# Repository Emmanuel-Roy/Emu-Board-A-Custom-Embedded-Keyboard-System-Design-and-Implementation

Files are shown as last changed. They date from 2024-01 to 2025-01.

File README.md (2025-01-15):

# Emu-Board: A Custom Embedded Keyboard System Design and Implementation
A Custom Keyboard Designed *Almost Entirely From Scratch.

Images:





Things Designed From Scratch

  -PCB (Using KiCad and ScottoKeebs Footprint and Symbol Libraries)

  -Casing (Using Ruby to laser cut the acrylic)

  -Keyboard Matrix Firmware Code (Using KMK Firmware to do the majority of the processing.)

Components Bought:

  -77 Key Switches (Boba U4T)

  -77 1N4148 Diodes

  -Durock Plate Mounted Stabilizers

  -Raspberry Pi Pico

  -Keycaps

  -M.2 Screws and Standoffs

I used the following resources to help with this project.

  -https://matt3o.com/anatomy-of-a-keyboard/

  -http://www.keyboard-layout-editor.com/

  -http://builder.swillkb.com/

  -https://github.com/joe-scotto/scottokeebs/tree/main/Extras/ScottoKicad

  -https://www.youtube.com/watch?v=8WXpGTIbxlQ

  -https://www.youtube.com/watch?v=8WXpGTIbxlQ

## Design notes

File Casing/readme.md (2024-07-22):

Use trotec ruby to lazer cut.

The height of the raspberry pi is roughy 54 mm, I a rectangle to account for it in kiCAD.

I also made the space between the screw posts and outer layer of wood too small, I'd recommend more clearance because my standoff have mostly broken off.

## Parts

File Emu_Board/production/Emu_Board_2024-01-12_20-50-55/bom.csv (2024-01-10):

Designator | Footprint | Quantity | Value | LCSC Part #
D1, D10, D11, D12, D13, D14, D15, D16, D17, D18, D19, D2, D20, D21, D22, D23, D24, D25, D26, D27, D28, D29, D3, D30, D31, D32, D33, D34, D35, D36, D37, D38, D39, D4, D40, D41, D42, D43, D44, D45, D46, D47, D48, D49, D5, D50, D51, D52, D53, D54, D55, D56, D57, D58, D59, D6, D60, D61, D62, D63, D64, D65, D66, D67, D68, D69, D7, D70, D71, D72, D73, D74, D75, D76, D77, D8, D9 | Diode_DO-35 | 77 | Diode
S1, S10, S11, S12, S13, S14, S15, S16, S17, S18, S19, S2, S20, S21, S22, S23, S24, S25, S26, S29, S3, S30, S31, S32, S33, S34, S35, S36, S37, S38, S39, S4, S40, S43, S44, S45, S46, S47, S48, S49, S5, S50, S51, S52, S53, S56, S57, S58, S59, S6, S60, S61, S62, S63, S64, S65, S67, S7, S75, S76, S77, S8, S9 | MX_PCB_1.00u | 63 | Keyswitch
S27 | MX_PCB_2.00u | 1 | Keyswitch
S28, S41 | MX_PCB_1.50u | 2 | Keyswitch
S42 | MX_PCB_1.75u | 1 | Keyswitch
S54, S55 | MX_PCB_2.25u | 2 | Keyswitch
S66 | MX_PCB_2.75u | 1 | Keyswitch
S68, S69, S70, S72, S73, S74 | MX_PCB_1.25u | 6 | Keyswitch
S71 | MX_PCB_6.25u | 1 | Keyswitch
U2 | Raspberry_Pi_Pico | 1 | Raspberry_Pi_Pico

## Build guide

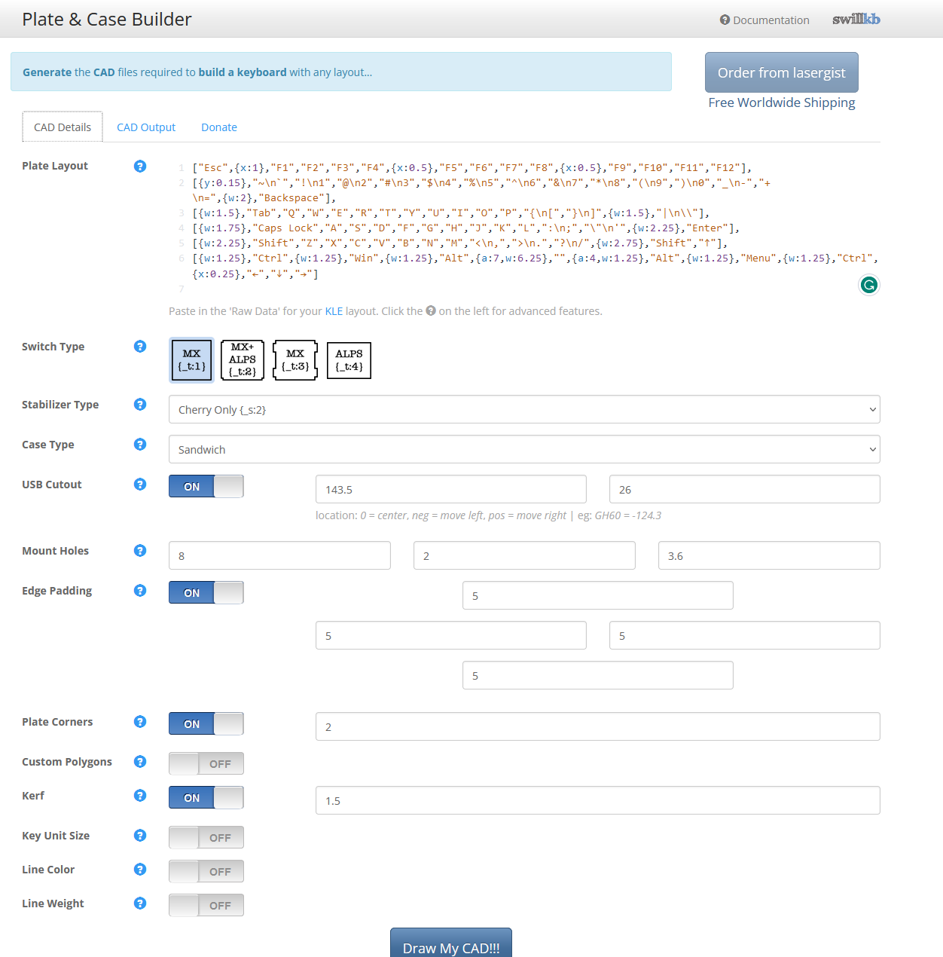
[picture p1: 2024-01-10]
CAD Requirementrs (Find the Kerf of the lazer printers).png

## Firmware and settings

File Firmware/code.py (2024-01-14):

import board    
from kmk.kmk_keyboard import KMKKeyboard
from kmk.keys import KC
from kmk.extensions.media_keys import MediaKeys


EMUBOARD = KMKKeyboard()

EMUBOARD.col_pins = (board.GP6,board.GP7,board.GP8,board.GP9,board.GP10,board.GP11,board.GP12,board.GP13,board.GP14,board.GP15,board.GP16,board.GP17,board.GP18,board.GP19)
EMUBOARD.row_pins = (board.GP0,board.GP1,board.GP2,board.GP3,board.GP4,board.GP5)
EMUBOARD.extensions.append(MediaKeys())


EMUBOARD.keymap = [
    [KC.ESCAPE, KC.F1, KC.F2, KC.F3, KC.F4, KC.F5, KC.F6, KC.F7, KC.F8, KC.F9, KC.F10, KC.F11, KC.F12, KC.NO,
     KC.GRAVE, KC.N1, KC.N2, KC.N3, KC.N4, KC.N5, KC.N6, KC.N7, KC.N8, KC.N9, KC.N0, KC.MINUS, KC.EQUAL, KC.BSPACE,
     KC.TAB, KC.Q, KC.W, KC.E, KC.R, KC.T, KC.Y, KC.U, KC.I, KC.O, KC.P, KC.LBRACKET, KC.RBRACKET, KC.BSLASH,
     KC.CAPSLOCK, KC.A, KC.S, KC.D, KC.F, KC.G, KC.H, KC.J, KC.K, KC.L, KC.SCOLON, KC.QUOTE, KC.ENTER, KC.NO,
     KC.LSHIFT, KC.Z, KC.X, KC.C, KC.V, KC.B, KC.N, KC.M, KC.COMMA, KC.DOT, KC.SLASH, KC.RSHIFT, KC.UP,KC.NO,
     KC.LCTRL, KC.LGUI, KC.LALT, KC.SPACE, KC.RALT, KC.MEDIA_PLAY_PAUSE, KC.RCTRL, KC.LEFT, KC.DOWN, KC.RIGHT, KC.NO, KC.NO, KC.NO
    ]
]

if __name__ == '__main__':
    EMUBOARD.go()
 
